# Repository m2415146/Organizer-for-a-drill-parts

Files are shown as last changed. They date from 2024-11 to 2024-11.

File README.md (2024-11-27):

# Organizer-for-a-drill-parts
This is a training task for making an organizer for a drill parts  

**i need to make an organizer for a parts like this**  
  
  
  
## Intro

**Parameters:**   
numbers of parts - 15-20;  
one size from one point and different one from other;  

**Highly recommended:**  
combine these materials - plywood 3mm thiсkness, acrylic, polycarbonate, 3d printing materials - FFF (PLA, PETg)  
## Inspiring Ideas  
**Basic principle**  
Эскизы-6  
**Holder type**  
  
**Forms**  
  
  
  
  

## Current analogues  
**From [prusaprintables](https://www.printables.com/) to find a current good ideas**  

[link1](https://www.printables.com/model/267239-er11-collet-organizerstorageboxholder)  
  

[link2](https://www.printables.com/model/155953-collet-holder-organizer-for-pliers-er32-collet-org)  
  

[link3](https://www.printables.com/model/772351-er16-collet-organizer-box)  
  

[link4](https://www.printables.com/model/842395-end-mill-and-er11-collet-organizer)  
  

## Overall  
Its a good idea to use the principle of "putting it in the hole" - its better than my idea of "use as attachments" drill parts, because of less material and easier to make it. Also its a good idea to add a 
drawer for additional parts. I want to think about how to make a acrylic/polycarbonate cap for it: for this moment i dont know how to make it with round angles for better view. I have an idea to use a 3d printed bearing to make a movable holder, but with limitations of time much effective to realize it in next projects in my opinion.
Also: for structural parts i prefer to use a PETg filament (better than PLA because of hydrolytic degradation can break it through 1+ year), holder will be in the box and if it brokes (box) - major to use it by itself. I dont like how to looks plywood but I'll think about how to use it: as a holder (because its faster than i can print it) or for the perimeter of the box  

## Measurements  
By calipers  

  

tsanga_vysokotochnaya_woodwork_er16 03 00_er16_d3_3_tsanga_vysokotochnaya_0_01mm_1678970209_2  

## 3d Modelling basic part
By Rhinoceros 8

Create a drill part  
  

Make a holder  
  
  

## Printing basic part

3D Printer - Flashforge A5M  


Slicing in OrcaSlicer  
  

Material - Geeetech PETg (standart settings for Flashforge 5m 0.4 Nozzle Flashforge PETg)
  

Printing in action  

https://github.com/user-attachments/assets/81df22e7-c970-43f2-8cb9-a2a00037cc8c

Got it!  


## 3d Modelling box for other things  
The harderst part for me. I spent half a day for it

Create a box and a printed cap with attachments to holder  
  

  

Holes have been added because of less material, weight and some less time of printing, design also. later, during slicing, it became obvious that it made sense only for the sake of design - for example, the time gain was only 4 minutes. The most difficult stages of the simulation were the matching of the parts with each other. the desire to make the box collapsible lost out to my desire to go to bed, so I tried to print the whole box. To adapt to printing, I also modeled drawer guides with theoretically acceptable overhangs for printing  
  

## Printing box  

3D Printer - Flashforge A5M  

Slicing in Orcaslicer  


Material - Geeetech PETg (standart settings for Flashforge 5m 0.4 Nozzle Flashforge PETg)  

Printing in action  

https://github.com/user-attachments/assets/591f5c42-22fd-4a34-a2b3-855c0cb37e73  

Got it!  
  

## Problems

There is problem with box:  
photo_5323817246105135485_y  

https://github.com/user-attachments/assets/0c6e3d64-1ee0-49c6-86d6-83343827146b

Why did this happen?  

Overhangs? Orcaslicer said about it  
  

- No, because we have the same part printed on the other side and we have modified the model to better print overhangs.
  
Cooling?
- No, because not the whole part is in the strings
  
For sure problems in model. We can see this in Orcaslicer


But in Rhino its not easy to see it  
  

## Problem solving  

i thought about different varients to solve this. Major point - try to avoid reprinting the box. For sure if you do this project for the first time you must avoid this problem and use correct model.   

   1. Measurement different thickness of defected wall to find the difference
   photo_5326069045918820083_y

By chance, we managed to conduct a test for falling from a height of 1.5 meters onto a tile  
photo_5326069045918820325_y  

   3. Model a path for wall (i will print it if after the drawer test, this will be necessary)
      
      
   4. Drilling a box

By dental micromotor Rehne Sense A3  
photo_5326069045918820327_y  

In action  

https://github.com/user-attachments/assets/90e0d156-f785-4068-a063-ab61cbd37572  

Got it  
photo_5326069045918820326_y  

## Modelling drawer  

So many time i've spent to engage the pull-out mechanism...  
It was also important not to increase its thickness excessively in order to save material and save free space. I had to abandon the previous complex rail system and integrate a system consisting of a small touch point in 2 planes on each side, also created cutouts in the box for the protruding parts of the former part of the box. I'll make it easier next time.  The holes are made to reduce printing time, save material and reduce the weight of the box itself in order to reduce the load on the sliding elements of the box and the box itself  

  

Unfortunately, this method led to the appearance of overhanging elements that would require either support during 3D printing and subsequent post-processing, as well as could worsen the sliding of the drawer. I managed to adapt the internal cavities for the rails to 3D printing, there is no upper sliding part, so with a heavy heart I decided to divide the model into 2 parts and glue it later. if it does not withstand the load, I have hope that the box will still function

  

  

## Printing drawer  

3D Printer - Flashforge A5M

SLicing by Orcaslicer  
Material - Geeetech PETg (standart settings for Flashforge 5m 0.4 Nozzle Flashforge PETg)  
  

In action  

https://github.com/user-attachments/assets/3bcc4333-d597-43b2-b65e-62a3246af166

Got it  

photo_5326069045918820685_y  

Drawer in action  

https://github.com/user-attachments/assets/0ca51161-b320-43d8-a2cc-3c5e39b406ac  

**Problems**  

PETg comes off the table, despite the fact that I use a lot of glue. I also noticed that the box itself is also deformed at the corners, especially on the side where the printing was unsuccessful due to a defect in the model - I probably should think about uniform cooling during printing or better isolate the printer from ventilation with an open window. But may be this is a reason why it works together (box and drawer) - because both are deformed. So, this is not a bug, but a feature  

photo_5326069045918820686_y

## Printing additional parts  

3D Printer - Flashforge A5M

SLicing by Orcaslicer  cap for a box   
Material - Geeetech PETg (standart settings for Flashforge 5m 0.4 Nozzle Flashforge PETg)  

  

In action  

https://github.com/user-attachments/assets/371f283b-90c8-4eb4-ae72-51515384f0ad  

Got it  
photo_5325846648217266334_y  

**All together**  
photo_5325846648217266335_y

Creating a path to repair a box  
when I saw that the box was working, I decided that instead of the upper part of the drawer mount, it was worth printing the missing part of the inner wall of the box with a rail  

  

but when I loaded the model into the slicer, I saw the overhanging elements and changed it so that it was adapted to 3D printing  

PATH for repair box 2 0  

3D Printer - Flashforge A5M

SLicing by Orcaslicer    
Material - Geeetech PETg (standart settings for Flashforge 5m 0.4 Nozzle Flashforge PETg)  

Printing  

https://github.com/user-attachments/assets/98961e1c-b639-490a-8cd8-b6f9d957ea22  

Got it  
photo_5325846648217266355_y  

Problems with lenght. Perhaps I will solve this with the help of hand tools.  
photo_5325846648217266356_y  

## Problems solving  

Let's mark where you need to make a cut
photo_5328098448030949691_y   

A universal battery cutter is used for trimming  
photo_5328098448030949689_y  

In action  

https://github.com/user-attachments/assets/007f61a3-d2bc-402c-ac2d-c658694db286  

Got it  
photo_5328098448030949686_y  

We will glue the part to the box using cyanoacrylate glue  
photo_5328098448030949687_y  

Got it. 
photo_5328098448030949688_y  

it does not look perfect, there is also a gap between the rail at the box itself and the added part, but this does not affect the function. Also, the part will be hidden inside the box and invisible to an outside observer.  

Test drive  

https://github.com/user-attachments/assets/2b017a06-3dc3-45f5-bbf6-edb4367d7137  

## intermediate test  

photo_5328098448030949690_y  

In action  

https://github.com/user-attachments/assets/768d4e1c-632d-4511-aff7-0ba2212e646b  

## Add additional materials  

Acrylic  

I wanted to make the outer walls of the box out of plywood, but decided that acrylic would look nicer with green PETG. I had the idea to cut out a single piece with live loops, but the question arose as to how accurately the corners would be able to be made. so it was decided to divide into 2 parts and bend.  
Creating in CorelDraw with a helps from one of the teachers from FabLab (Thank you, Alexander!)  

photo_5328098448030950143_y  

Laser cut  

https://github.com/user-attachments/assets/872408ff-d58c-42d7-b00e-24e503963cf8  

It was decided to bend the obtained parts from acrylic using a homemade device for bending acrylic, which was in FabLab. By heating the metal thread by convection, the acrylic is heated  

photo_5328098448030950144_y  

you should wait until a heating line appears on the top surface of the acrylic, without allowing it to overheat, which will be noticeable by the fact that the part hanging in the air begins to tilt towards the table. then I applied the heated acrylic to the PETg box, carefully bent it and held it for a while to maintain its shape  

photo_5328098448030950145_y  

Got it    
photo_5328098448030950147_y  

then remove the film from the inside of the acrylic before gluing the acrylic to the box with cyanoacrylate glue  
photo_5328098448030950146_y  

we glue it and look at the result.  

photo_5328098448030950148_y  

After this, the PETg box parts can be glued together using cyanoacrylate adhesive. To prevent accidental gluing, I removed the drawer. The protruding parts of the holder itself (the uppermost section), which fit into the lid’s slots like a sieve, were left unglued. This allows time for settling (including shrinkage) and reduces the risk of incorrect positioning. The protective film remains on the outer surface for now.  

photo_5327836631119554560_y  

**Overall**
On the back of the box the acrylic parts could not be connected. Tomorrow I will try to solve this problem. to avoid this in the future, you can not only cut out an acrylic part on a laser machine before bending, but also engrave the line of the future bend for accuracy.  

Initially, I planned to add acrylic, because in the conditions of our task it was strongly recommended to use different materials, but the resulting result not only looks cool, but also gives rigidity to the walls made of PETg, which has elasticity  

## Problem solving  

I wanted to close the gap between the acrylic walls on the back of the box  

photo_5330568870269938649_y  

we measure it with a caliper  

photo_5330568870269938650_y  

an important task is to compensate for the uneven contour of the mapping, which arose due to PETg shrinkage during 3d printing  

the first model was unsuccessful, but I noticed it only after trimming it. the error was at the stage of removing unnecessary lines after modeling in rhinoceros  

photo_5330568870269938651_y  

then I took into account the errors and carefully corrected the cropping contour in rhinoceros  

photo_5330568870269938652_y  

in action  

https://github.com/user-attachments/assets/cebae0ec-4a27-4283-8e7d-e661fe97d95b  

got it  

photo_5330568870269938653_y  

during the fitting, a new problem was discovered: on the left side, the part fit well into the grooves, but on the right (from the one where the greatest slope was) it did not.  

photo_5330568870269938654_y  

photo_5330568870269938655_y  

I decided to adjust the right side of the part using a needle file, but due to lack of time I did not have time to do it completely  

photo_5330568870269938659_y  

in order for this part to fall into place well, I had to use a dental micromotor  

it didn't work out very smoothly, but I've already spent too much time on the project to perfect such details  

photo_5343948964707296419_y  

I glued it with cyanoacrylate glue. the difference in the surfaces is because I have already removed the film from this part, but not from those on the sides of the box  

photo_5343948964707296420_y  

## Add a drawer handle with text  

The slot in the drawer was modeled to put a pen with an inscription there. there will also be a qr code with a link to this project so that you can view it from a user who may have problems. the qr will be modeled in CorelDRAW, in Rhino I inserted it for visualization  

  

**Important notes**  

since the task of uploading a qr code for laser cutting may be relevant for other users, I created a separate project and described there in a short form the solution to this problem.  

[Qr-code-for-laser-cut](https://github.com/m2415146/Qr-code-for-laser-cut/tree/main)  

the outline for cutting out the sign with text for the drawer was modeled in the rhinoceros program, two-color acrylic was chosen as the material - gold surface and black backing  

  

qr code which was modeled in coreldraw program was imported for cutting. also at this stage, the width of the arrow and the font of the inscriptions at the top and bottom were increased  

photo_5330568870269938656_y  

in action  

https://github.com/user-attachments/assets/bad29915-b9ae-4f7f-b641-10bab0e1079d  

Got it  

photo_5330043097553429044_y  

Unfortunately, the QR code turned out to be unreadable for my iPhone’s camera, and when I took a photo of it and moved it to the gallery, it was not recognized by the system. Most likely this happened due to the small size of the code in combination with the high laser power during engraving. I'll try to either reduce the laser power to re-engrave this part, or find a way to generate a qr code with larger elements    

in an attempt to solve this problem, I tried to cut out a new qr code with slightly different settings  

laser cut in action  

https://github.com/user-attachments/assets/67e1da9c-d266-463a-8b07-de5399721a07  

photo_5343948964707296411_y  

Unfortunately, the qr code still turned out to be unreadable. for more than an hour, I tried to find a service that would help me create code from larger parts, but failed. for this reason, it was decided to use a text link  

editing in CorelDraw  

photo_5343948964707296412_y

laser cut in action  

https://github.com/user-attachments/assets/1fc98e9d-86f7-420c-897f-67b353a8b0f9

goi it  

photo_5341424228311885119_y (1)  

despite the deformed edge of the groove on top, due to the elasticity of the material, it must be functional  

## Additional part for handle drawer  

Since I initially planned to cut out a sign with text entirely from a thick sheet of acrylic and did not know in advance what thickness options were available in FAbLab, I made a fairly wide groove in the box with a margin that could be filled using a 3D printed part printer  

this insert had to be modeled in two parts, since one was supposed to act as support for the sign, and the other to give it rigidity  

creating in RhinoCeros  

  

  

in order to add variety to the materials, I wanted to print these details from PLA  

Slicing in Orcaslicer  

  

3d printer - Flashforge A5m, filament - High Speed PLA eSun, standart settings for 0.4 nozzle for Flashforge PLA  

unfortunately, I had several unsuccessful attempts to print from this material  

photo_5339084519107584048_y  

photo_5339084519107584047_y  

I decided to use a different material: PETG from GEEETECH with the same settings that I used to print other parts of the box  

Slicing in Orcaslicer  

in order to avoid the deformation that was with PETG, from which the rest of the box was printed, my colleague advised to rinse the printing table well. I also added a skirt to avoid the corners of the model coming off.  

  

  

I used wire cutters to cut off the printed skirt pieces. I polished the remaining uneven surface from the top edge using a dental machine  

photo_5343948964707296413_y  

the result of fitting an acrylic plate with text to the holder  

photo_5343948964707296415_y  

to glue the parts to each other, I used cyanoacrylate glue  

photo_5343948964707296414_y  

the result of gluing. unfortunately, the acrylic plate was somewhat crookedly glued from one edge, but this did not prevent it from being fixed to the drawer  

photo_5343948964707296416_y  

from inside  

photo_5343948964707296417_y  

photo_5343948964707296418_y  

## Add plywood  

the way to apply plywood in this project is to make an additional overlay on the top of the holder. a possible additional option would be a greater degree of detail fixation  

Creating a model in Rhinoceros by extract surface command and saving this in .dxf for CorelDraw and adapting for laser cut  

  

  

after removing the extra lines, the markup color was replaced with red, which in our settings corresponds to the clipping, and black corresponds to the grading  

photo_5330568870269938660_y  

in action  

https://github.com/user-attachments/assets/9e342deb-39f6-4dea-aeec-417d49ffa481  

got it  

photo_5330568870269938661_y  

one side of the plywood showed visual signs of carbon deposits that had occurred during laser cutting. I turned the part over to the cleaner side and glued it to the top surface of the holder using cyanoacrylate glue  

got it. In this photo you can see that the edge of the plywood on the left protrudes slightly above the surface of the petg holder. Considering that the same model was used for modeling, this reason may be related to petg shrinkage during large-scale printing of the part. visually the holes match, so I don’t think this will affect its functionality.  

in this photo, a part of plywood (3 mm thick) glued to the holder is visible, and a sign with text and qr code made of two-tone acrylic is also embedded, which lies at an angle, since I have not yet made a holder for it from PETg, which should give thickness to the plate and increase its strength, acting as a handle. However, the final look of my project is almost ready  

photo_5330043097553429043_y

## About 3d modelling in rhinoceros 8  

since the description of the project turned out to be impressive enough not to load it, and also for convenience, I created a separate repository for the [list of commands](https://github.com/m2415146/List-of-commands-in-rhinoceros-8-for-modeling-an-organizer-for-collet/blob/main/README.md) in rhinoceros that I used to create this project  

##  Finished project  

all that remains is to remove the protective film from the acrylic walls, which I will do during the presentation of the project in the classroom  

photo_5343973888402516162_y  

https://github.com/user-attachments/assets/954870d1-88b1-4c48-8253-5ab28a4f0d49  

in action    

https://github.com/user-attachments/assets/a791bfff-6cda-4334-a892-9df4dd1e8bec  

## Qr code  

Since I still didn’t want to abandon the idea with the QR code, I decided to add it to the inside surface of the drawer. for this I used a thermal printer Niimbot b21  

  

Result  

photo_5343948964707296421_y
photo_5344042977246439769_y  

## Final photo from presentation  

photo_5348459913023711570_y  

## Final  test-drive  

photo_5348459913023712768_y  

photo_5348459913023712769_y  

https://github.com/user-attachments/assets/ca7d27c3-57b0-4f4e-b3d7-580acf0861d3

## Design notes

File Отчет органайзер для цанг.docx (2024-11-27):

Федеральное государственное автономное образовательное учреждение высшего образования

"Национальный исследовательский технологический университет "МИСИС"

Предмет: компьютерное проектирование и инжиниринг

“Органайзер для цанг”

Выполнил:

Синицын Д.С,

Студент 1 курса магистратуры

Группа МТМО 24-3

Программа “Технологии и материалы

цифрового производства” (ИТ)

руководитель: Тавитов А.Г.

Москва, 2024

Оглавление:

1. Введение - 3
2. План работы - 4
3. Мозговой штурм – 5
4. Существующие аналоги – 6
5. Изготовление держателя – 7
6. Изготовление выдвижного ящика – 9
7. Изготовление дополнительных элементов – 12
8. Результаты - 17
9. Выводы - 18
1. Введение

Перед нами была поставлена задача по разработке и изготовлению при помощи цифровых машин органайзера для инструментов, среди которых я выбрал устройство для хранения цанг к-016. Причина выбора: однотипность и соразмерность позволяет сэкономить время на измерении образцов, при этом сосредоточившись на основной задаче – моделировании и, собственно, изготовлении.

Изготовленный образец будет не только способом применить на практике знания, полученные в ходе занятий по дисциплине “компьютерное проектирование и инжиниринг”, но также, в случае, если образец окажется удачным по своей конструкции и прочностным свойствам, он будет применяться в лаборатории FabLab на базе НИТУ МИСИС для хранения соответствующих инструментов.

Дополнительной возможностью так же является ведение репозитория на платформе “github”, что позволит освоить навык пошагового документирования рабочего процесса, что может оказаться полезным в случае изготовления опытных образцов в рабочей практике.

В данном отчете описание не соответствует хронологическому процессу изготовления, который описан на проекте в “github” (https://github.com/m2415146/Organizer-for-a-drill-parts )

2. План работы
1) Мозговой штурм
2) Обзор некоторых уже существующих аналогов
3) Измерение опытного образца цанги
4) Изготовление основной части конструкции
5) Изготовление дополнительных частей конструкции
6) Возникшие проблемы и методы их решения
7) Результаты
8) Выводы

Мозговой штурм

Главное на этом этапе – дать полную волю фантазии и никакой критики. При помощи приложения “GoodNotes” на Ipad, используя apple pencil я сделал наброски своих смелых идей.

В основу я хотел взять принцип, чтобы цанги насаживались на специальный держатель (каждый).

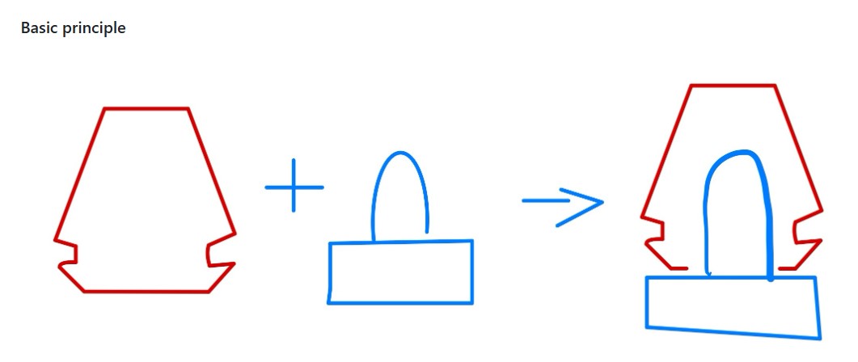
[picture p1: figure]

При помощи существующих инструментов 3д моделирования хотелось создать форму органайзера, которая будет напоминать гоночный шлем или ручную ракетницу с подъемным механизмом.

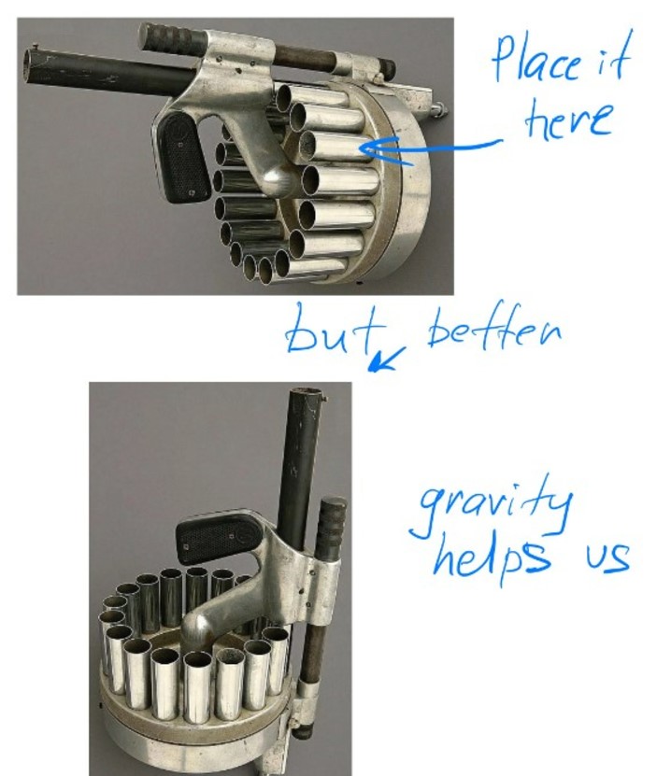
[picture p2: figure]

Разместить держатели планировал либо в одной плоскости, либо в виду двухэтажной конструкции. Возможно, с механизмом вращения, чтобы нужный образец мог “подъехать” к пользователю.

Существующие аналоги

Для того, чтобы оценить существующие аналоги я использовал сайт https://www.printables.com/. Здесь я обнаружил на мой взгляд более удачную конструкцию, в которой цанги помещались в специально смоделированные отверстия. Это позволило бы упростить как изготовление, так и сэкономить материал. На самом деле это так же позволило решить еще одну потенциальную проблему – несовпадение размеров, так как снаружи цанги были одинакового размера, но внутри отверстия различались по диаметру.

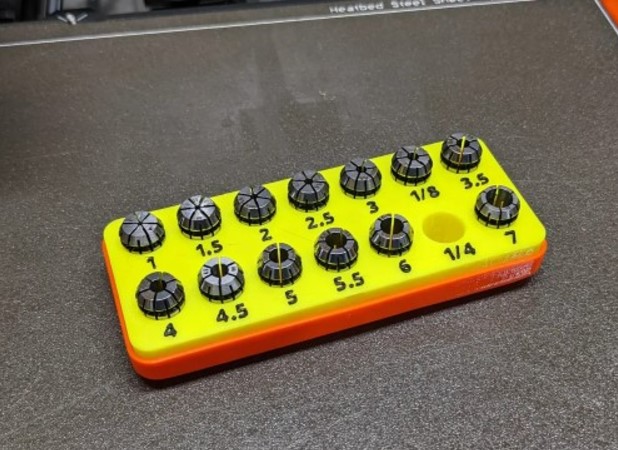
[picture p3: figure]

Также меня заинтересовала возможность реализации выдвижных ящиков: как с точки зрения конструкции, так и с точки зрения практической пользы, так как туда можно укладывать дополнительные детали.

Изготовление держателя

Я решил начать с изготовления самого держателя цанг. Это позволило бы мне сразу решить формальную задачу и, если бы я не успел доделать остальные части органайзера, задача была бы все равно выполнена.

Сначала произвел измерение цанги при помощи штангенциркуля.

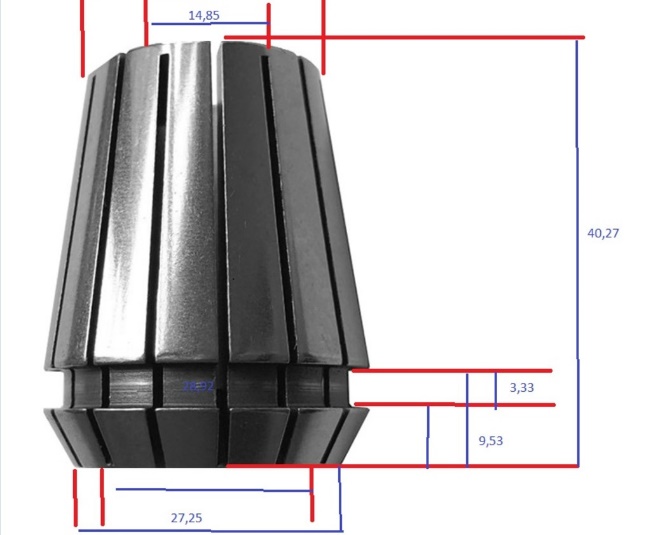
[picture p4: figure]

Используя полученные размеры смоделировал внешний контур цанги в RHinoCeros 8.

Затем смоделировал собственно держатель.

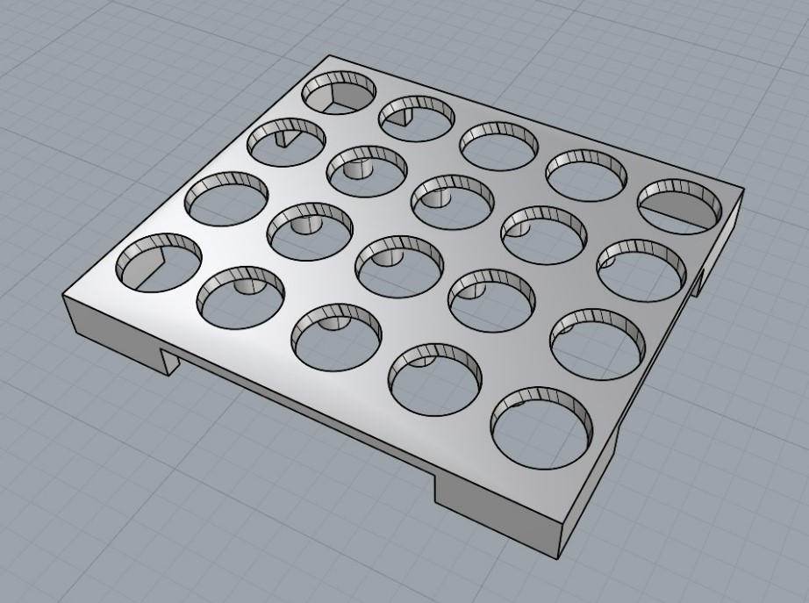
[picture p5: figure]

Держатель был распечатан на 3д принтере Flashforge A5M материалом Geeetech PETg.

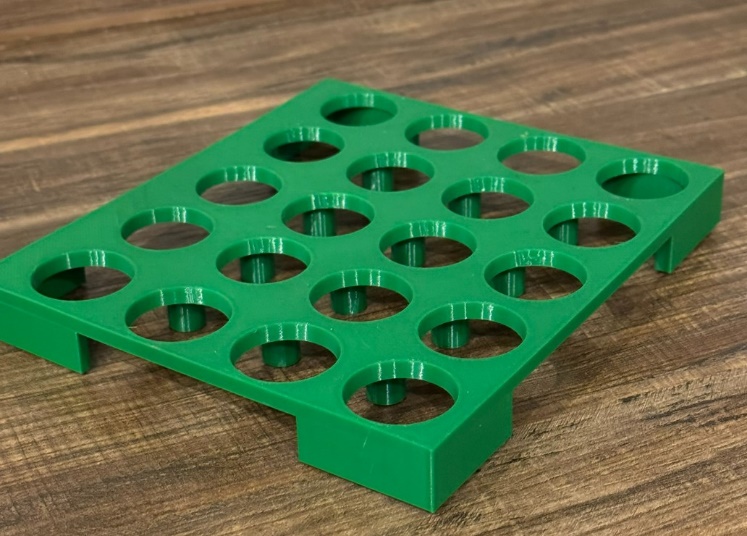
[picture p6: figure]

Учитывая такой ход работы мне пришлось использовать для создания остальных частей модульную конструкцию, которая бы собиралась при помощи пазов и использования клея.

Изготовление выдвижного ящика

Я начал с моделирования корпуса ящика с рельсами, которые бы обеспечивали скольжение.

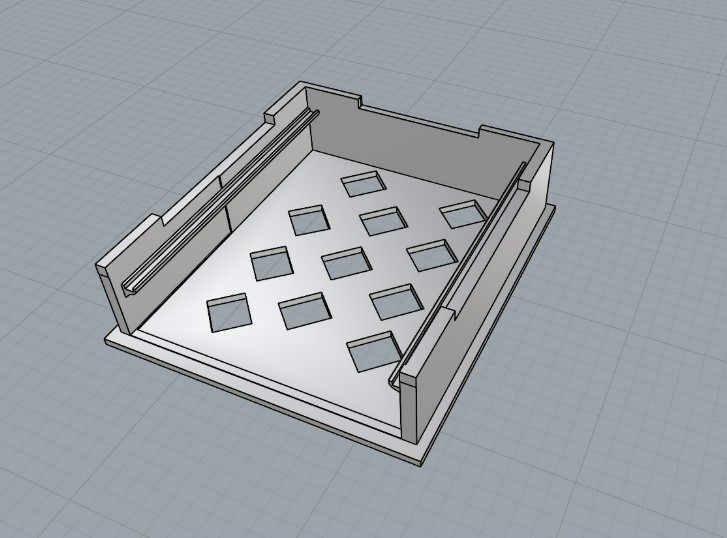
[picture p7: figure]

Также сразу смоделировал крышку для ящика, которая бы позволяла его использовать как отдельно от органайзера, так и выступала бы соединительным элементом и, в то же время, ребром жесткости для собственно держателя.

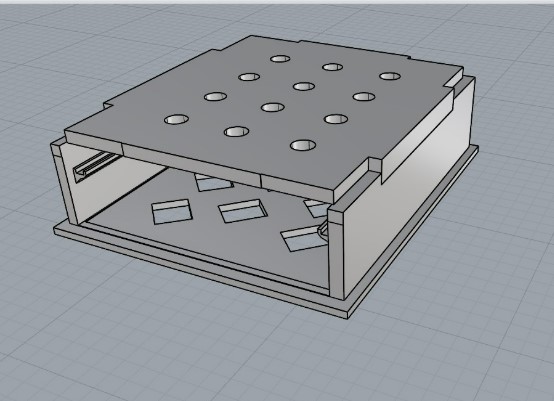
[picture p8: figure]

Учитывая, что выполнял эту задачу в первый раз, то проектировал слишком сложную форму рельсы.

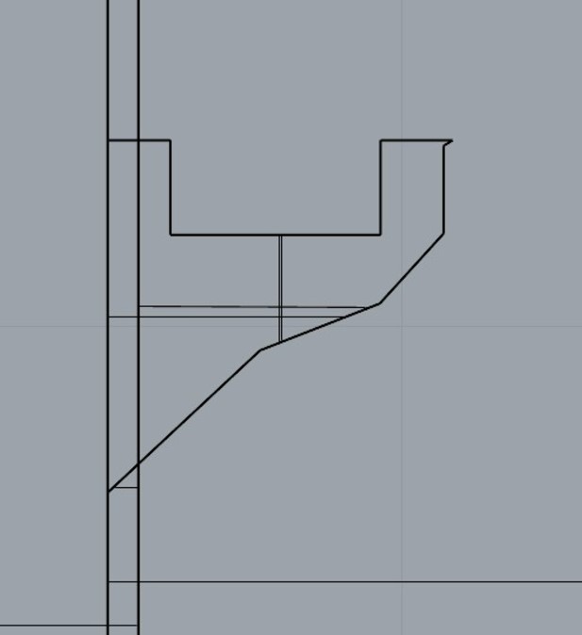
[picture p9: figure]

Так же распечатал из PETg.

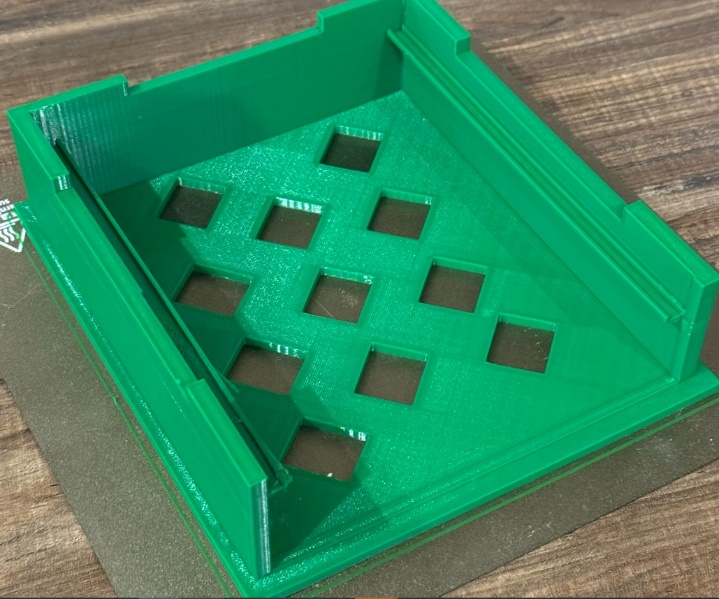
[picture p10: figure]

На этом этапе стало возможным моделировать сам выдвижной ящик.

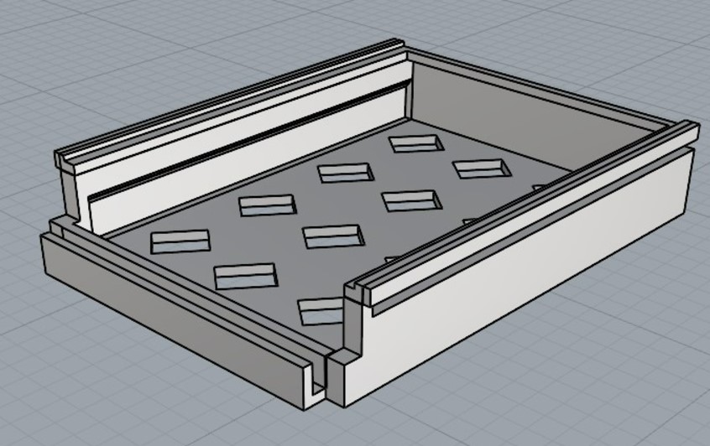
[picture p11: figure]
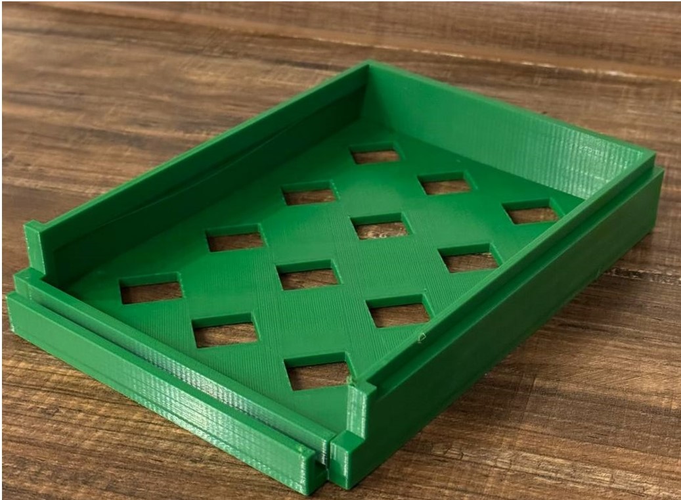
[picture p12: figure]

Конструкция была проверена в сборе.

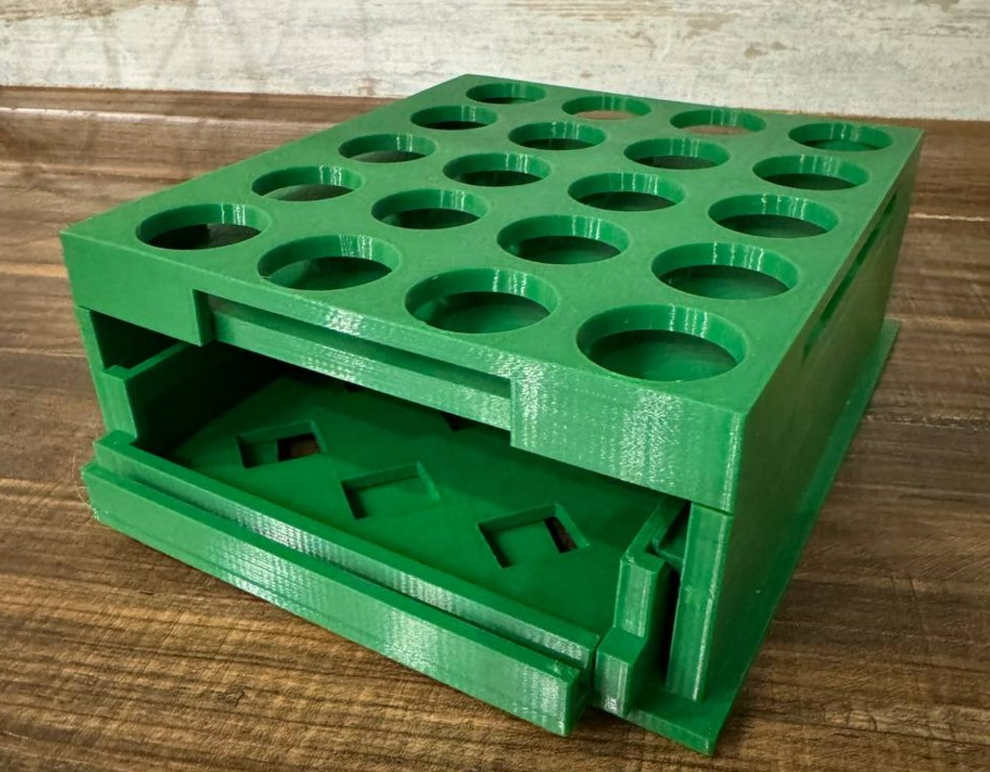
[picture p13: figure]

Создание дополнительных элементов.

В условиях задания требовалось комбинировать различные материалы. Периметр внешних стенок я решил сделать из акрила. Контур для их обрезки был выполнен в программе CorelDraw.

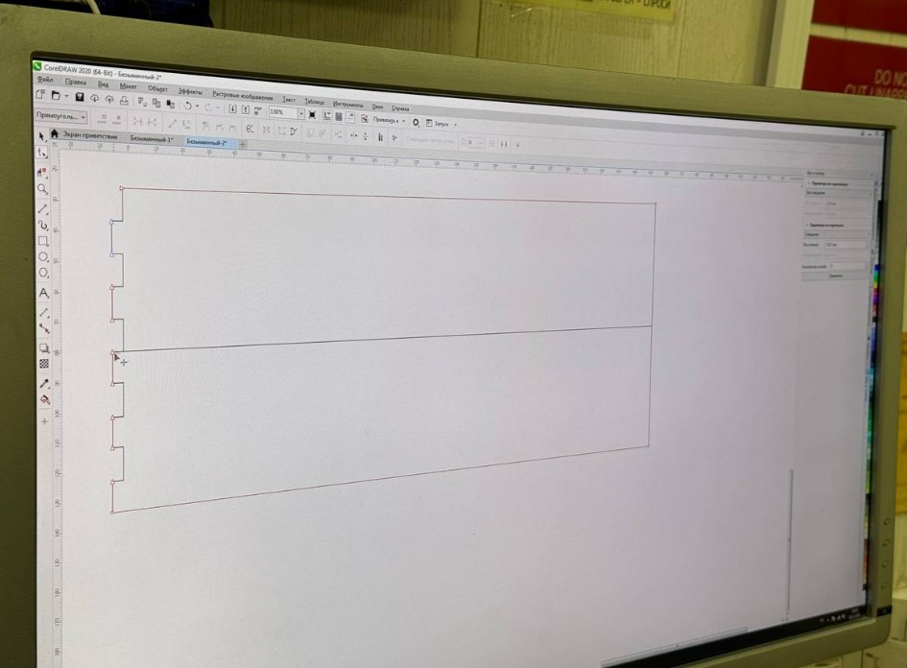
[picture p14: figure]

Акрил был вырезан на лазерном гравере. Изгибание акрила по контуру коробки было выполнено при помощи специального аппарата для нагревания акрила из FabLab.

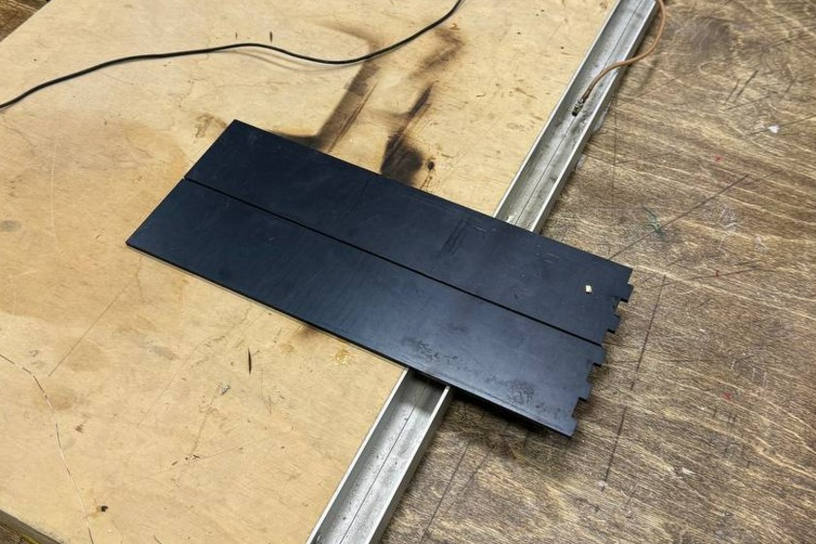
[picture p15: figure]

Изгибание акрила было выполнено на корпусе коробки.

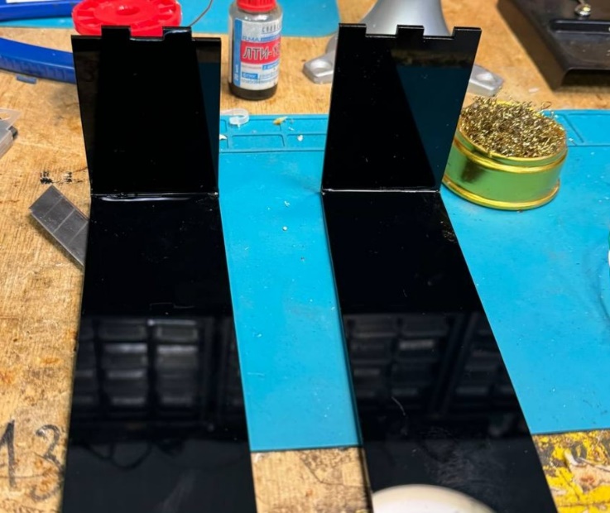
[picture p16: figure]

Панели были приклеены к корпусу при помощи метилакрилатного клея.

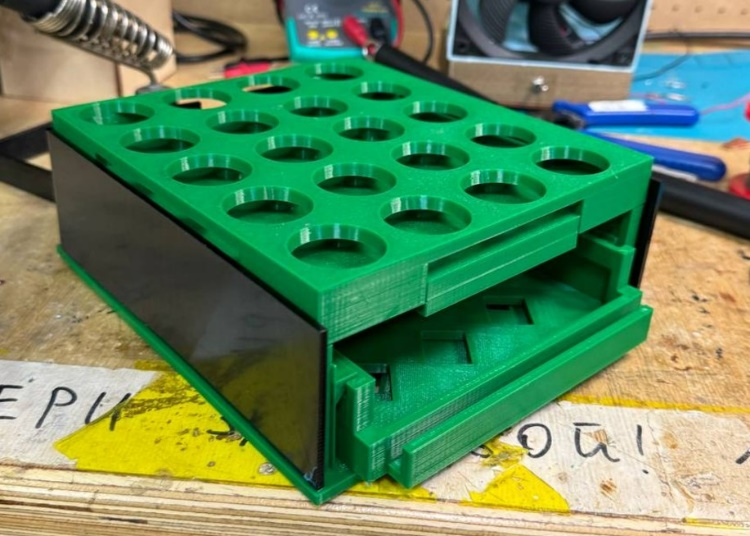
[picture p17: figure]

Для изготовления держателя ручки выдвижного ящика я использовал двухцветный акрил. Лицевую сторону смоделировал в программе RHinoCeros, перенес в CorelDraw и так же вырезал на лазерном резаке.

На лицевую сторону был нанесен адрес проекта на github, чтобы пользователи могли повторить проект, починить его в случае поломки или модернизировать.

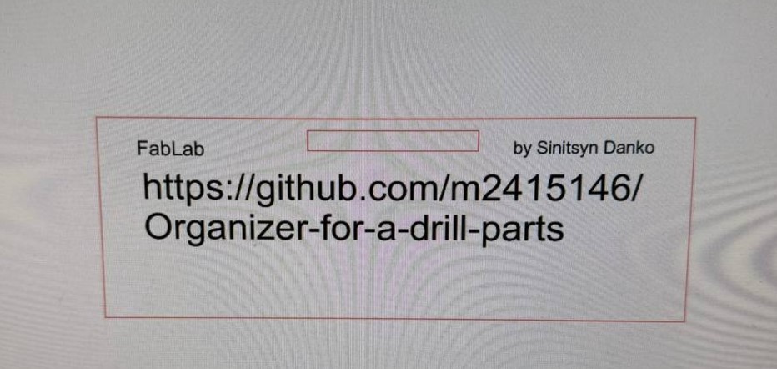
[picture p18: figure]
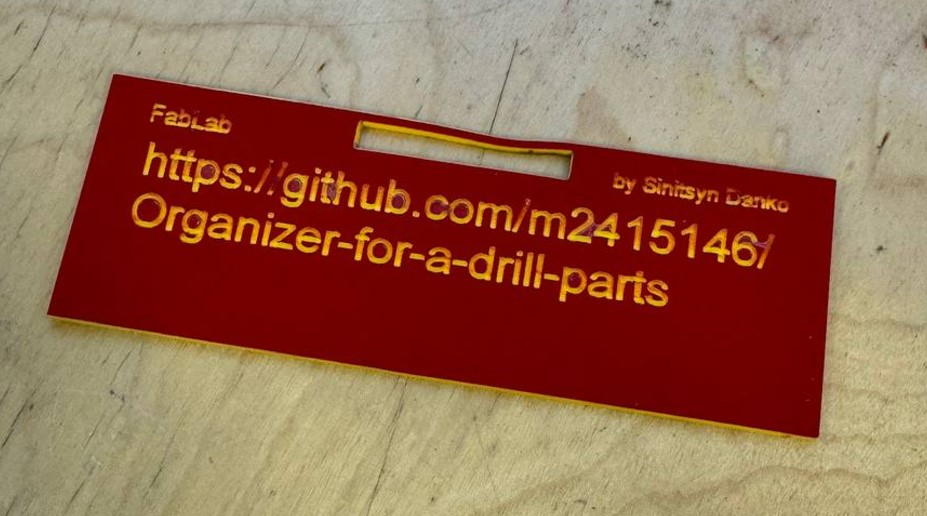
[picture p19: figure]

Для придания жесткости ручке ящика были смоделированы следующие детали:

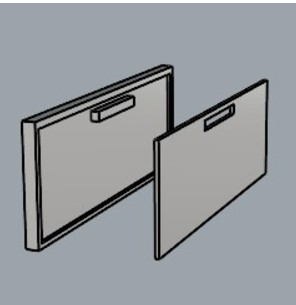
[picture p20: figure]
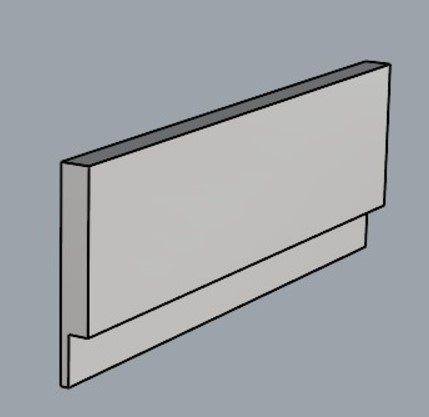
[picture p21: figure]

Они были напечатаны из PETg другого цвета, чем коробка. Приклеены при помощи метилакрилатного клея.

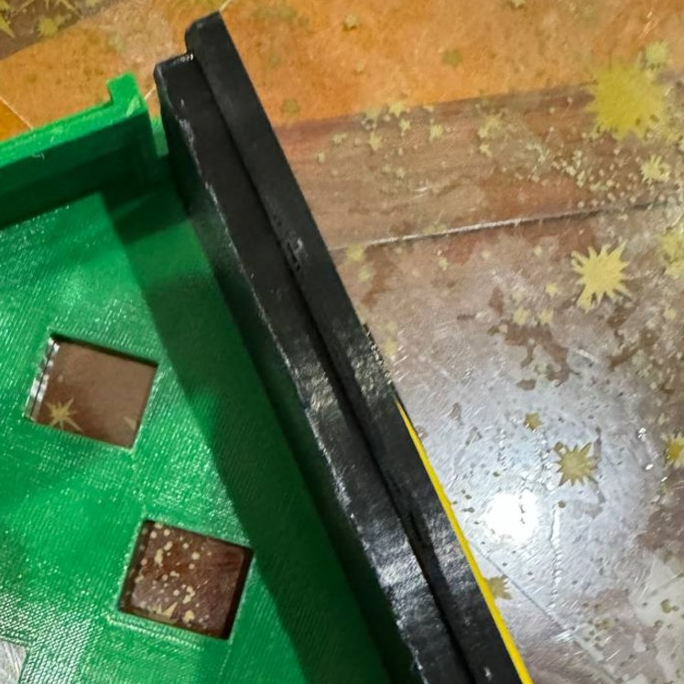
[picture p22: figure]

На верхней части ящика была добавлена накладка из фанеры, контур которой был смоделирован в RhinoCeros, перенесен в программу CorelDraw и, затем, изготовлен при помощи лазерного резака.

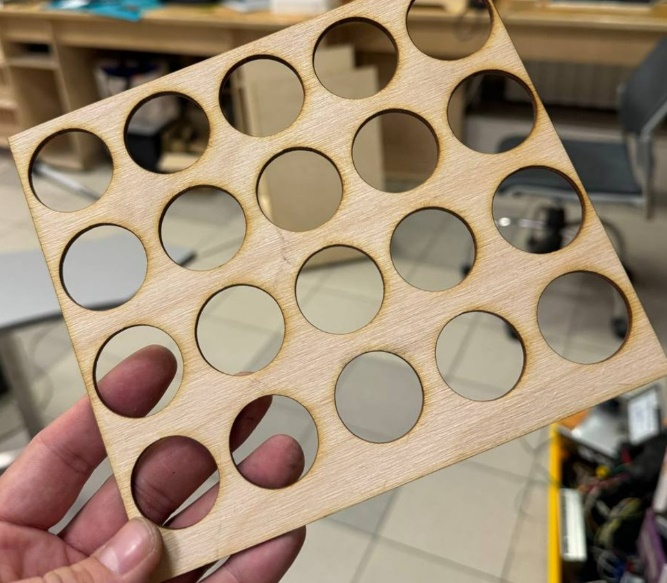
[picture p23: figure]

Затем деталь была приклеена при помощи метилакрилатного клея.

Вид готового изделия:

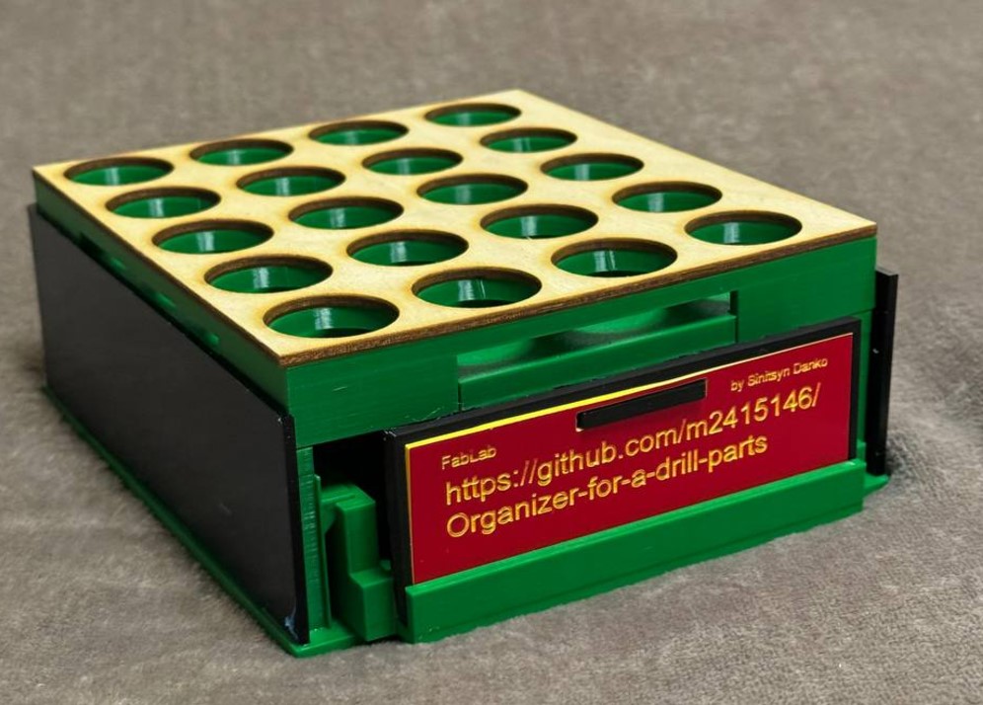
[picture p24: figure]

Результаты.

Получилось изготовить органайзер для цанг с использованием разных типов материалов.

Выводы.

Полученный опыт позволит в следующий раз планировать изготовление подобной конструкции с применением более простых решений, что позволит сэкономить время и трудозатраты.

Также в ходе работы возникали проблемы, описание которых и их решение я описал в проекте github по ссылке: https://github.com/m2415146/Organizer-for-a-drill-parts?tab=readme-ov-file

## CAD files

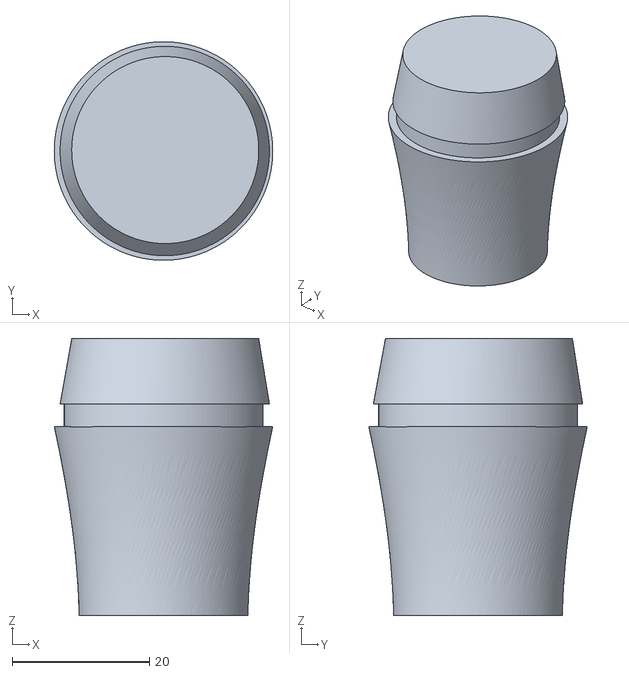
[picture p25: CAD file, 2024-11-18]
CAD/DRILL PART.stl
31.8 x 31.8 x 40.4

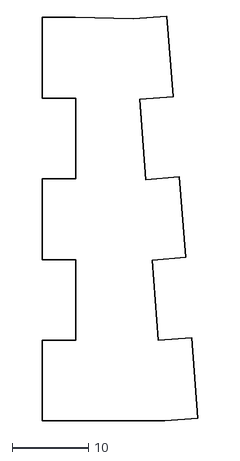
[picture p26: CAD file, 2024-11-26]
dxf/arcilyc part.dxf
20.5 x 53.2

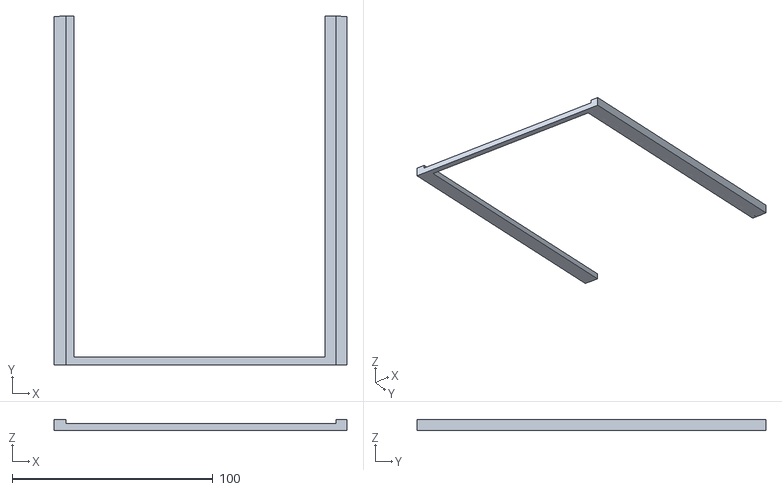
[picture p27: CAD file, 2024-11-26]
STL/dont need this/path drawer.stl
145.7 x 173.8 x 5.63

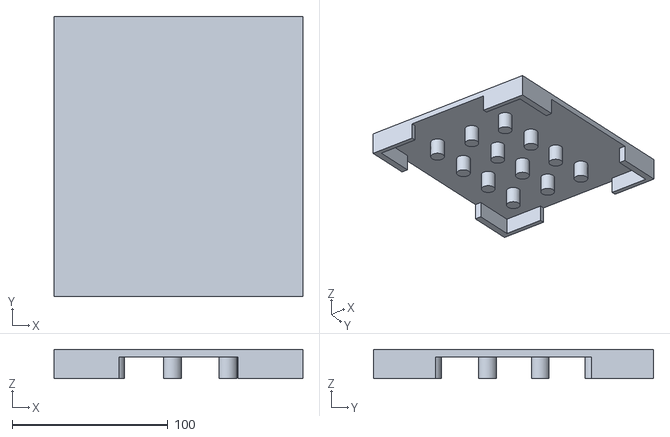
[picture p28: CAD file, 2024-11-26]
STL/HolderPetg.stl
160.0 x 180.0 x 18.9

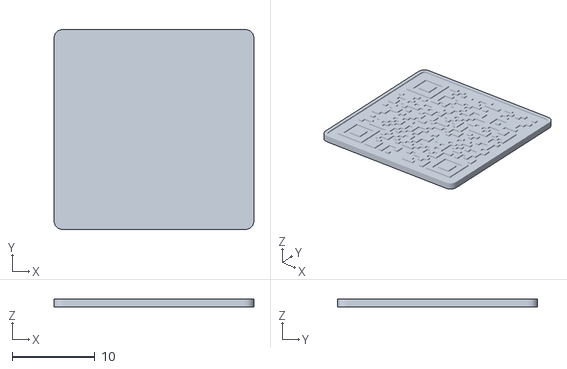
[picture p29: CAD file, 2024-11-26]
dxf/qr code 2.dxf
24.2 x 24.2 x 0.966

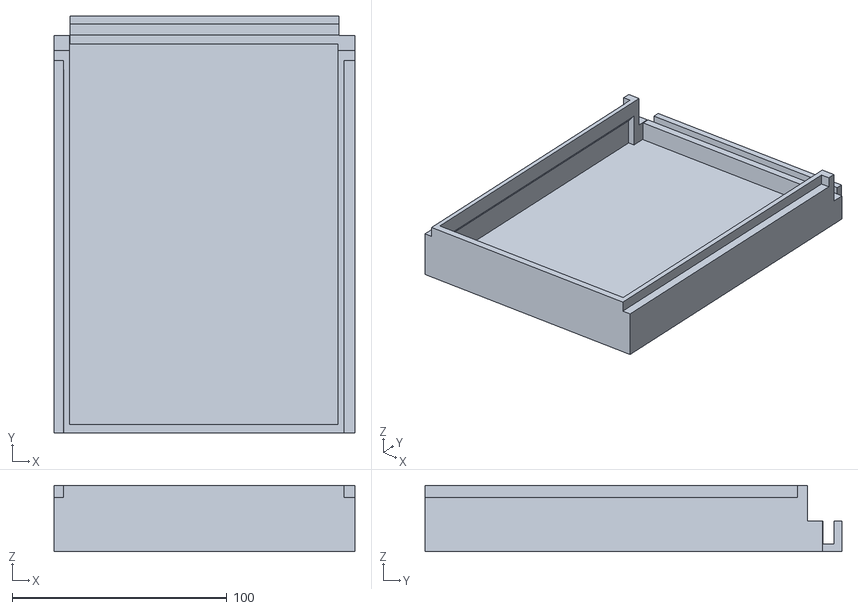
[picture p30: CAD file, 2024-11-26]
STL/dont need this/drawer.stl
140.0 x 194.2 x 30.8

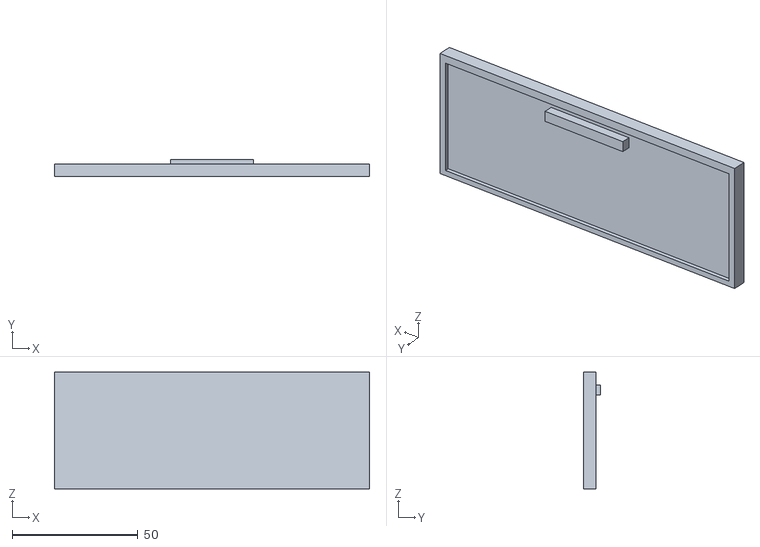
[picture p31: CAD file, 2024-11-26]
STL/holder2 pla.stl
125.1 x 6.93 x 46.4

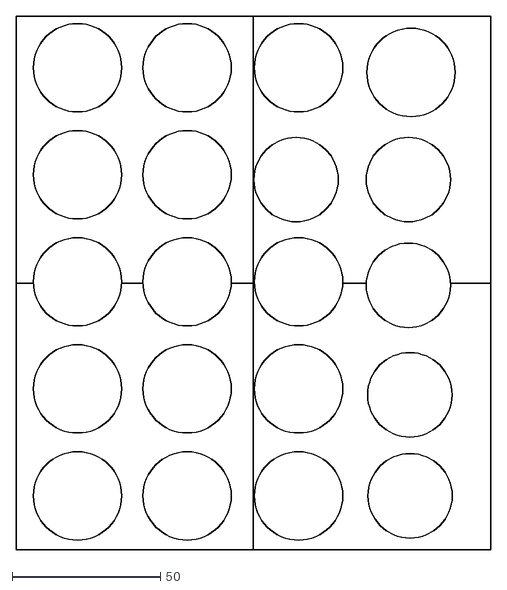
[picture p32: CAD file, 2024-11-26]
dxf/plywoodbox.dxf
160.0 x 180.0

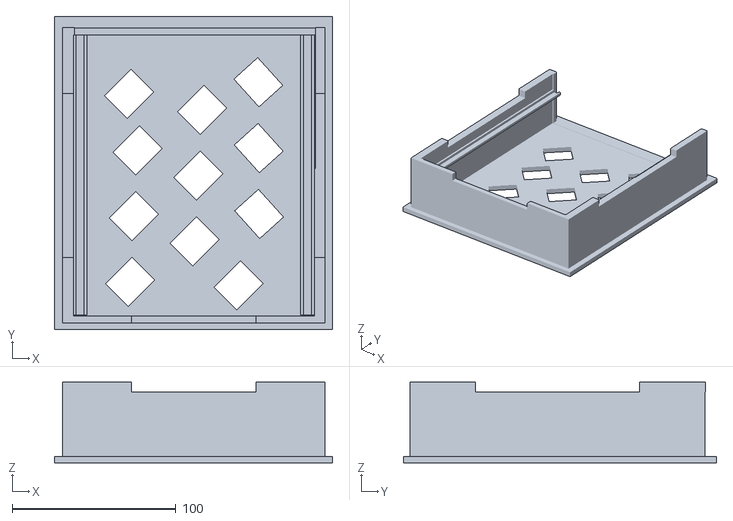
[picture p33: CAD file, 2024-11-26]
STL/box modified.stl
169.7 x 191.0 x 49.4

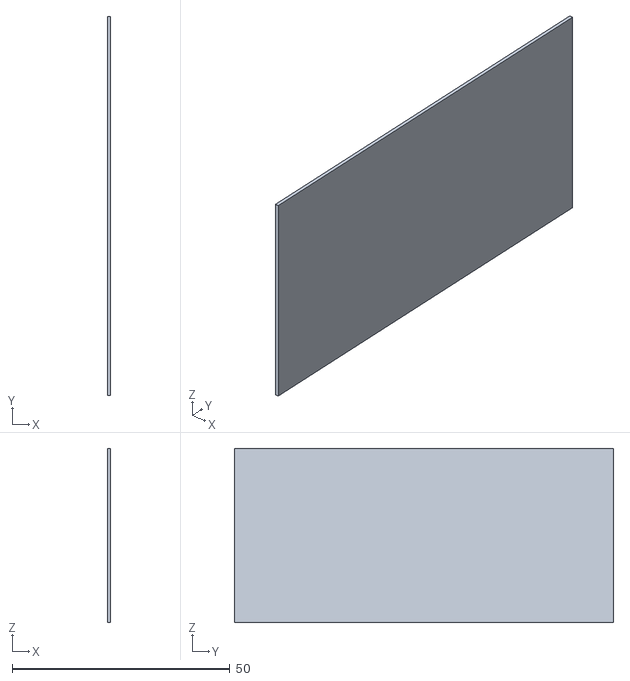
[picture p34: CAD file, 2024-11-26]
STL/dont need this/path wall.stl
0.7 x 87.0 x 40.0

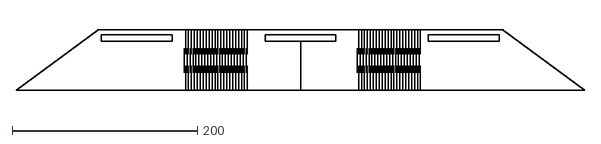
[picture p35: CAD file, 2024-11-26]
dxf/acrylic for box.dxf
614.0 x 65.0

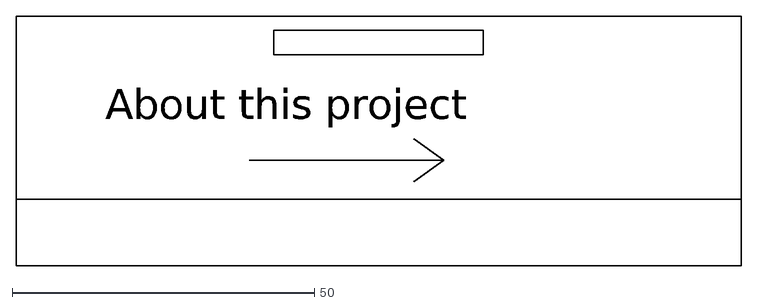
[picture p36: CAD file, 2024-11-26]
dxf/qr code.dxf
About this project

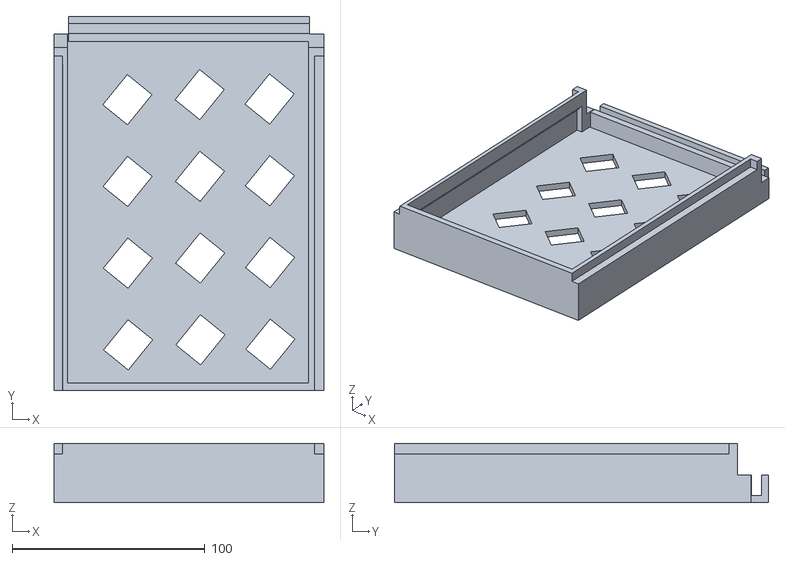
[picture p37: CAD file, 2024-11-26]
STL/drawer.stl
140.0 x 194.2 x 30.8

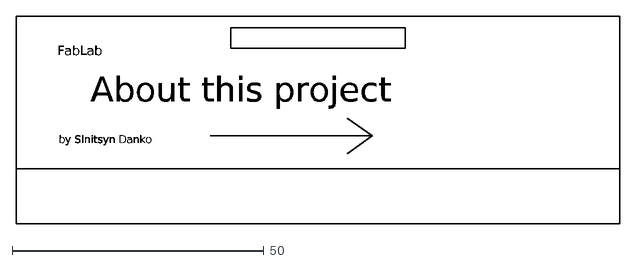
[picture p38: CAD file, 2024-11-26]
dxf/text for box.dxf
FabLab
by SInitsyn Danko
About this project

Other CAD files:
STL/Collet.stl
STL/PATH for repair box.stl
dxf/drill for plywood.dxf
STL/powerline for holder.stl
CAD/Holder with Drill Parts.3dm
CAD/HolderPetg.stl
Rhino8Project/holder for text.3dm
STL/box.stl
STL/cap for box.stl
dxf/Acrylic part true.dxf

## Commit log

2024-11-18 Upd 1.4.md
    Add current analogues + overall (my ideas about project)
2024-11-18 Upd 1.5.md
    Add a model drill part from Rhino
2024-11-18 Huge update.md
    add modelling box, videos of printing, problems with modelling and a photos of ready holder
2024-11-18 Add g-code, stl's and Rhino-project
    [box.stl, cap for box.stl]
2024-11-19 Add printed box.md
2024-11-19 Upd printed information.md
2024-11-19 Upd repair part printing.md
2024-11-19 Upd got all printed parts, but one more problem.md
2024-11-25 Add holder, text and glue it.md
